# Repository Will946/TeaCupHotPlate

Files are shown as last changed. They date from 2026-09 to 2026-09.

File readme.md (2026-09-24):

**Tea Cozy Hotplate**
=====================================

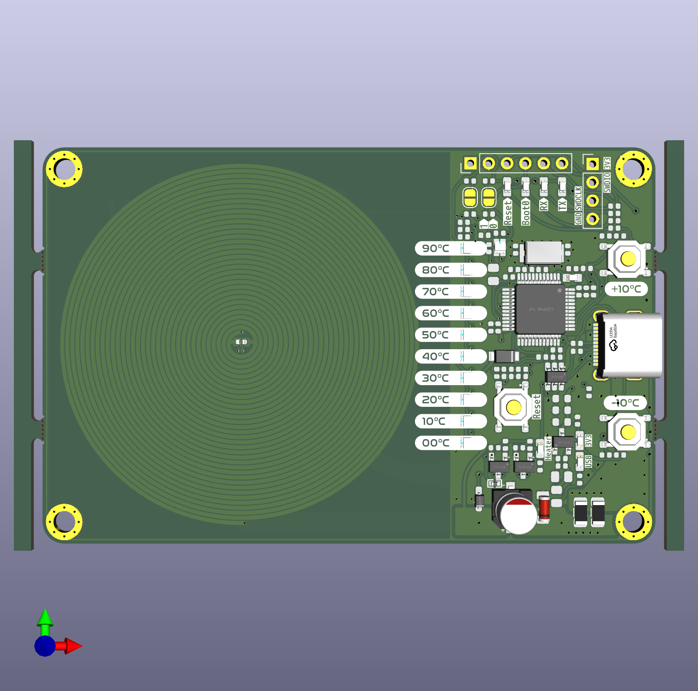
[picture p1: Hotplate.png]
PCB Render

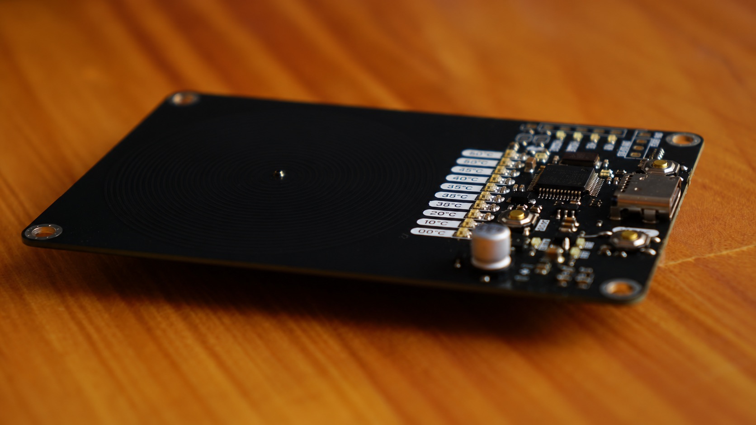
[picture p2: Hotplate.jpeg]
PCB Photo


### Overview

The Tea Cozy Hotplate is a USB-C powered, closed-loop temperature-controlled hotplate sized to sit under a single cup of tea. An STM32F103C8T6 ("Blue Pill" class MCU) reads a thermistor bonded to the underside of the heating coil, PWM drives two low-side NMOS switches to regulate power into a spiral PCB heater trace, and reports the current setpoint on a ten segment WS2812B ("Neopixel") LED bar that doubles as a 0 to 90 degrees C temperature dial. Two buttons let you nudge the setpoint up or down in 10 degree steps, and the whole board is bus powered off a single USB-C cable, with no separate power brick required.

### How It Works
**Power in.** 5V arrives on the USB-C receptacle (`J2`), passes through a pair of 1.5A resettable (PTC) fuses on VBUS, and is clamped by an `SRV05` ESD protection array on D+/D- and the CC lines. A single 2.2 ohm sense resistor pair plus 5.1kΩ pull downs on CC1/CC2 tell the upstream USB-C source the board is a fixed 5V/1.4A(ish) legacy sink. There is no PD negotiation chip, just resistor based CC termination, so any 5V USB-C source works. A `XC6206P332MR` LDO steps 5V down to a clean 3.3V rail for the MCU, LEDs, and sensors. A Zener (`D2`, ZMM5V6) sits across VBUS as extra transient protection.

**The heater.** The "hotplate" itself is not a separate component, it is a spiral trace etched directly into the PCB copper, measuring roughly 3.75 ohms in the assembled board, generated in KiCad with its built in Coil Generator tool (see the JLCPCB Heater Coil section below for the exact settings and trace math). Two `AO3400A` N-channel MOSFETs (`U3`/`U4`) sit low side between the coil and ground, each gated through a 4.7kΩ series resistor off the MCU's `Hotplate_EN` PWM line (rated for up to about 33kHz switching per the schematic notes). A flyback diode (`D1`, 1N5819WS Schottky) protects the switches from inductive kickback. The STM32 runs a PWM duty cycle proportional to the error between the setpoint and the measured coil temperature, essentially a bang bang or PID control loop over a resistive heater, similar to a soldering iron controller.

**Temperature sensing.** Two 47kΩ NTC thermistors are read as simple resistor divider ADC inputs. One (`Temp_Coil`) is thermally bonded near the heating coil to close the control loop, and a second (`Temp_Mosfet`) monitors the driver FETs so firmware can back off PWM if the switches themselves start overheating, giving thermal protection headroom beyond just controlling cup temperature.

**Display and setpoint.** Ten `WS2812B` addressable RGB LEDs, one per 10 degree step from 0 to 90 degrees C, are chained off a single data line (`Neopixel_Bus`) driven directly by an MCU GPIO, with no separate LED driver IC needed. Two tactile buttons (`SW2`/`SW3`, "Up"/"Down" in the schematic) step the setpoint in 10 degree increments, and the firmware lights LEDs up to the current setpoint.

**Programming and debug.** The board exposes both an SWD header (`SWDIO`/`SWDCLK`/GND/3V3) for use with an ST-Link V2, and a separate serial header (`MCU_TX`/`MCU_RX`/`Reset`/`BOOT0`) with its own status LEDs, so firmware can be flashed over SWD or bootloaded over UART without opening a case. Dedicated `Reset` and `BOOT0` push buttons plus solder jumpers (`JP1`/`JP2`) let you force the STM32 into its UART bootloader without needing to touch the board with tweezers.

### Features

* Closed-loop temperature control, plus or minus 2 degrees C accuracy
* Compact design fits most tea cups
* 10 segment addressable LED bargraph for setpoint/temperature display (0 to 90 degrees C in 10 degree steps)
* Up/down buttons for setpoint adjustment
* Powered entirely via USB-C (5V, about 1.4A budget, PTC fused)
* Dual NTC thermistors, one for coil temp (control loop), one for driver FET temp (protection)
* STM32F103C8T6 microcontroller, 72MHz Arm Cortex-M3
* Dedicated SWD and UART programming headers with BOOT0/Reset buttons for field reflashing

### Specifications

#### STM32 Specifications

* **CPU**: Arm Cortex-M3 @ 72MHz
* **Flash**: 64KB
* **RAM**: 20KB
* **Package**: LQFP-48

#### Components

* **Microcontroller**: STM32F103C8T6
* **LDO Regulator**: XC6206P332MR (5V to 3.3V)
* **ESD Protection**: SRV05 (USB D+/D-, CC1/CC2)
* **Fuse**: 2 x 1.5A Resettable Fuses (VBUS)
* **USB Connector**: USB-C Receptacle
* **Heater Driver**: 2 x AO3400A NMOS (low-side switching), 4.7kΩ gate resistors, 1N5819WS flyback diode
* **Heating Element**: ~3.75Ω Spiral PCB Coil (34 turns, 1 layer, 50mm outer diameter, 0.55mm trace width, 0.15mm spacing)
* **Temperature Sensors**: 2 x 47kΩ NTC Thermistor (coil + driver FET)
* **Display**: 10 x WS2812B addressable RGB LEDs (0-90°C bargraph)
* **User Input**: Up/Down setpoint buttons, Reset button, BOOT0 button

### Assembly and Programming

* Program the STM32 microcontroller using an ST-Link V2 via the SWDIO header, or bootload over the UART header (`MCU_TX`/`MCU_RX`) using the `BOOT0`/`Reset` buttons or `JP1`/`JP2` jumpers to force bootloader mode.

## JLCPCB Heater Coil (1mm PCB with 1oz/ft^2)

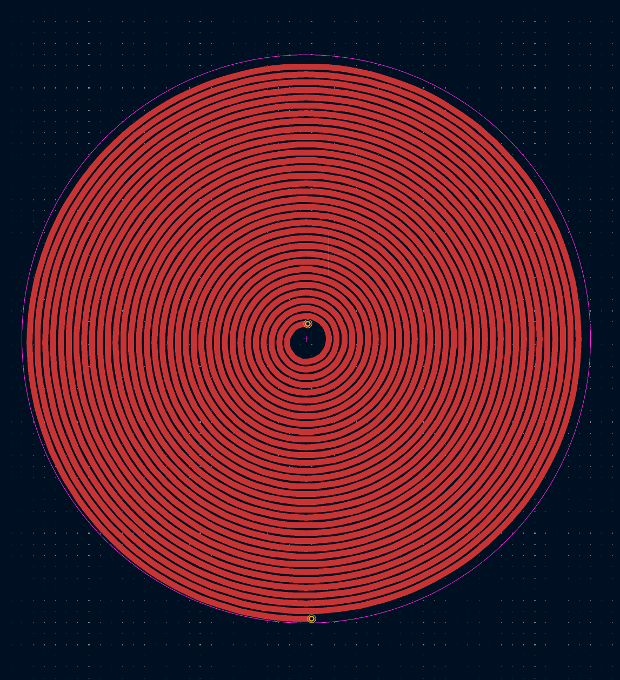
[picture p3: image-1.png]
Heater Coil PCB Trace

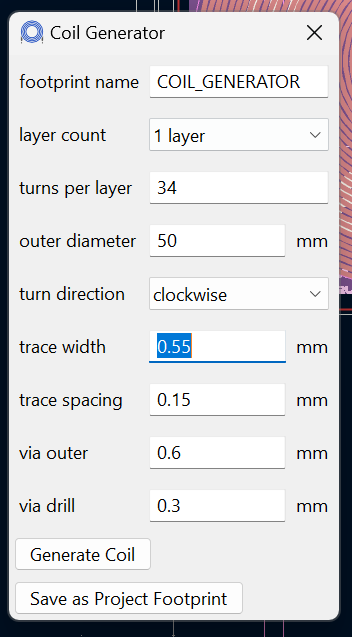
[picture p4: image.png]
KiCad Coil Generator Settings


* **Trace**: 2.8m length, 0.55mm width, 1oz/ft^2
* **Calculated Resistance**: 2.47Ω (assuming 0.000017Ω.mm)
* **Real-World Resistance**: 3.75Ω (calculated to be 0.0000258Ω.mm)

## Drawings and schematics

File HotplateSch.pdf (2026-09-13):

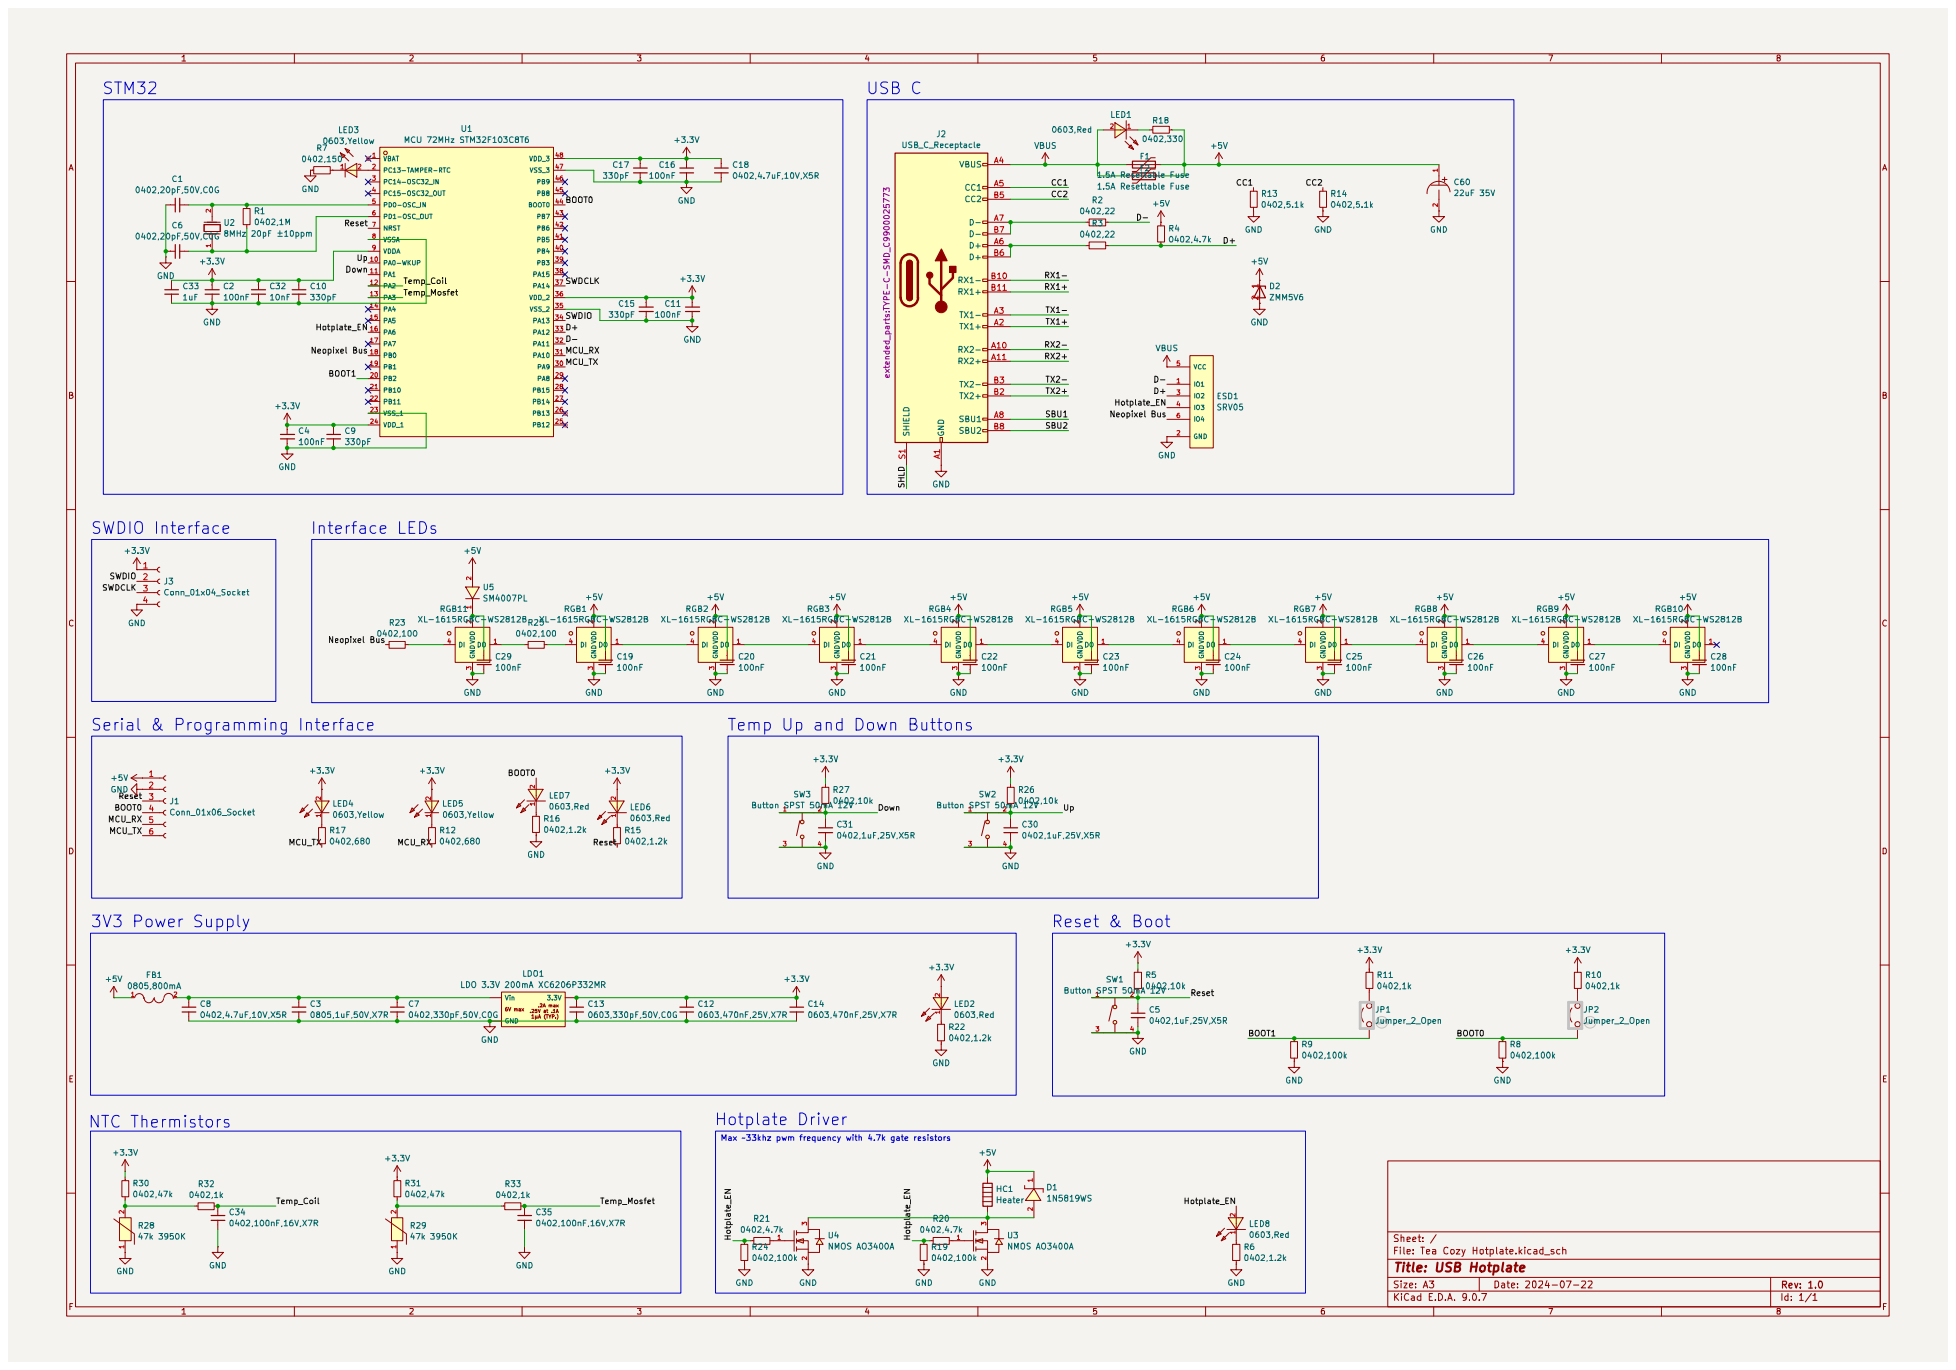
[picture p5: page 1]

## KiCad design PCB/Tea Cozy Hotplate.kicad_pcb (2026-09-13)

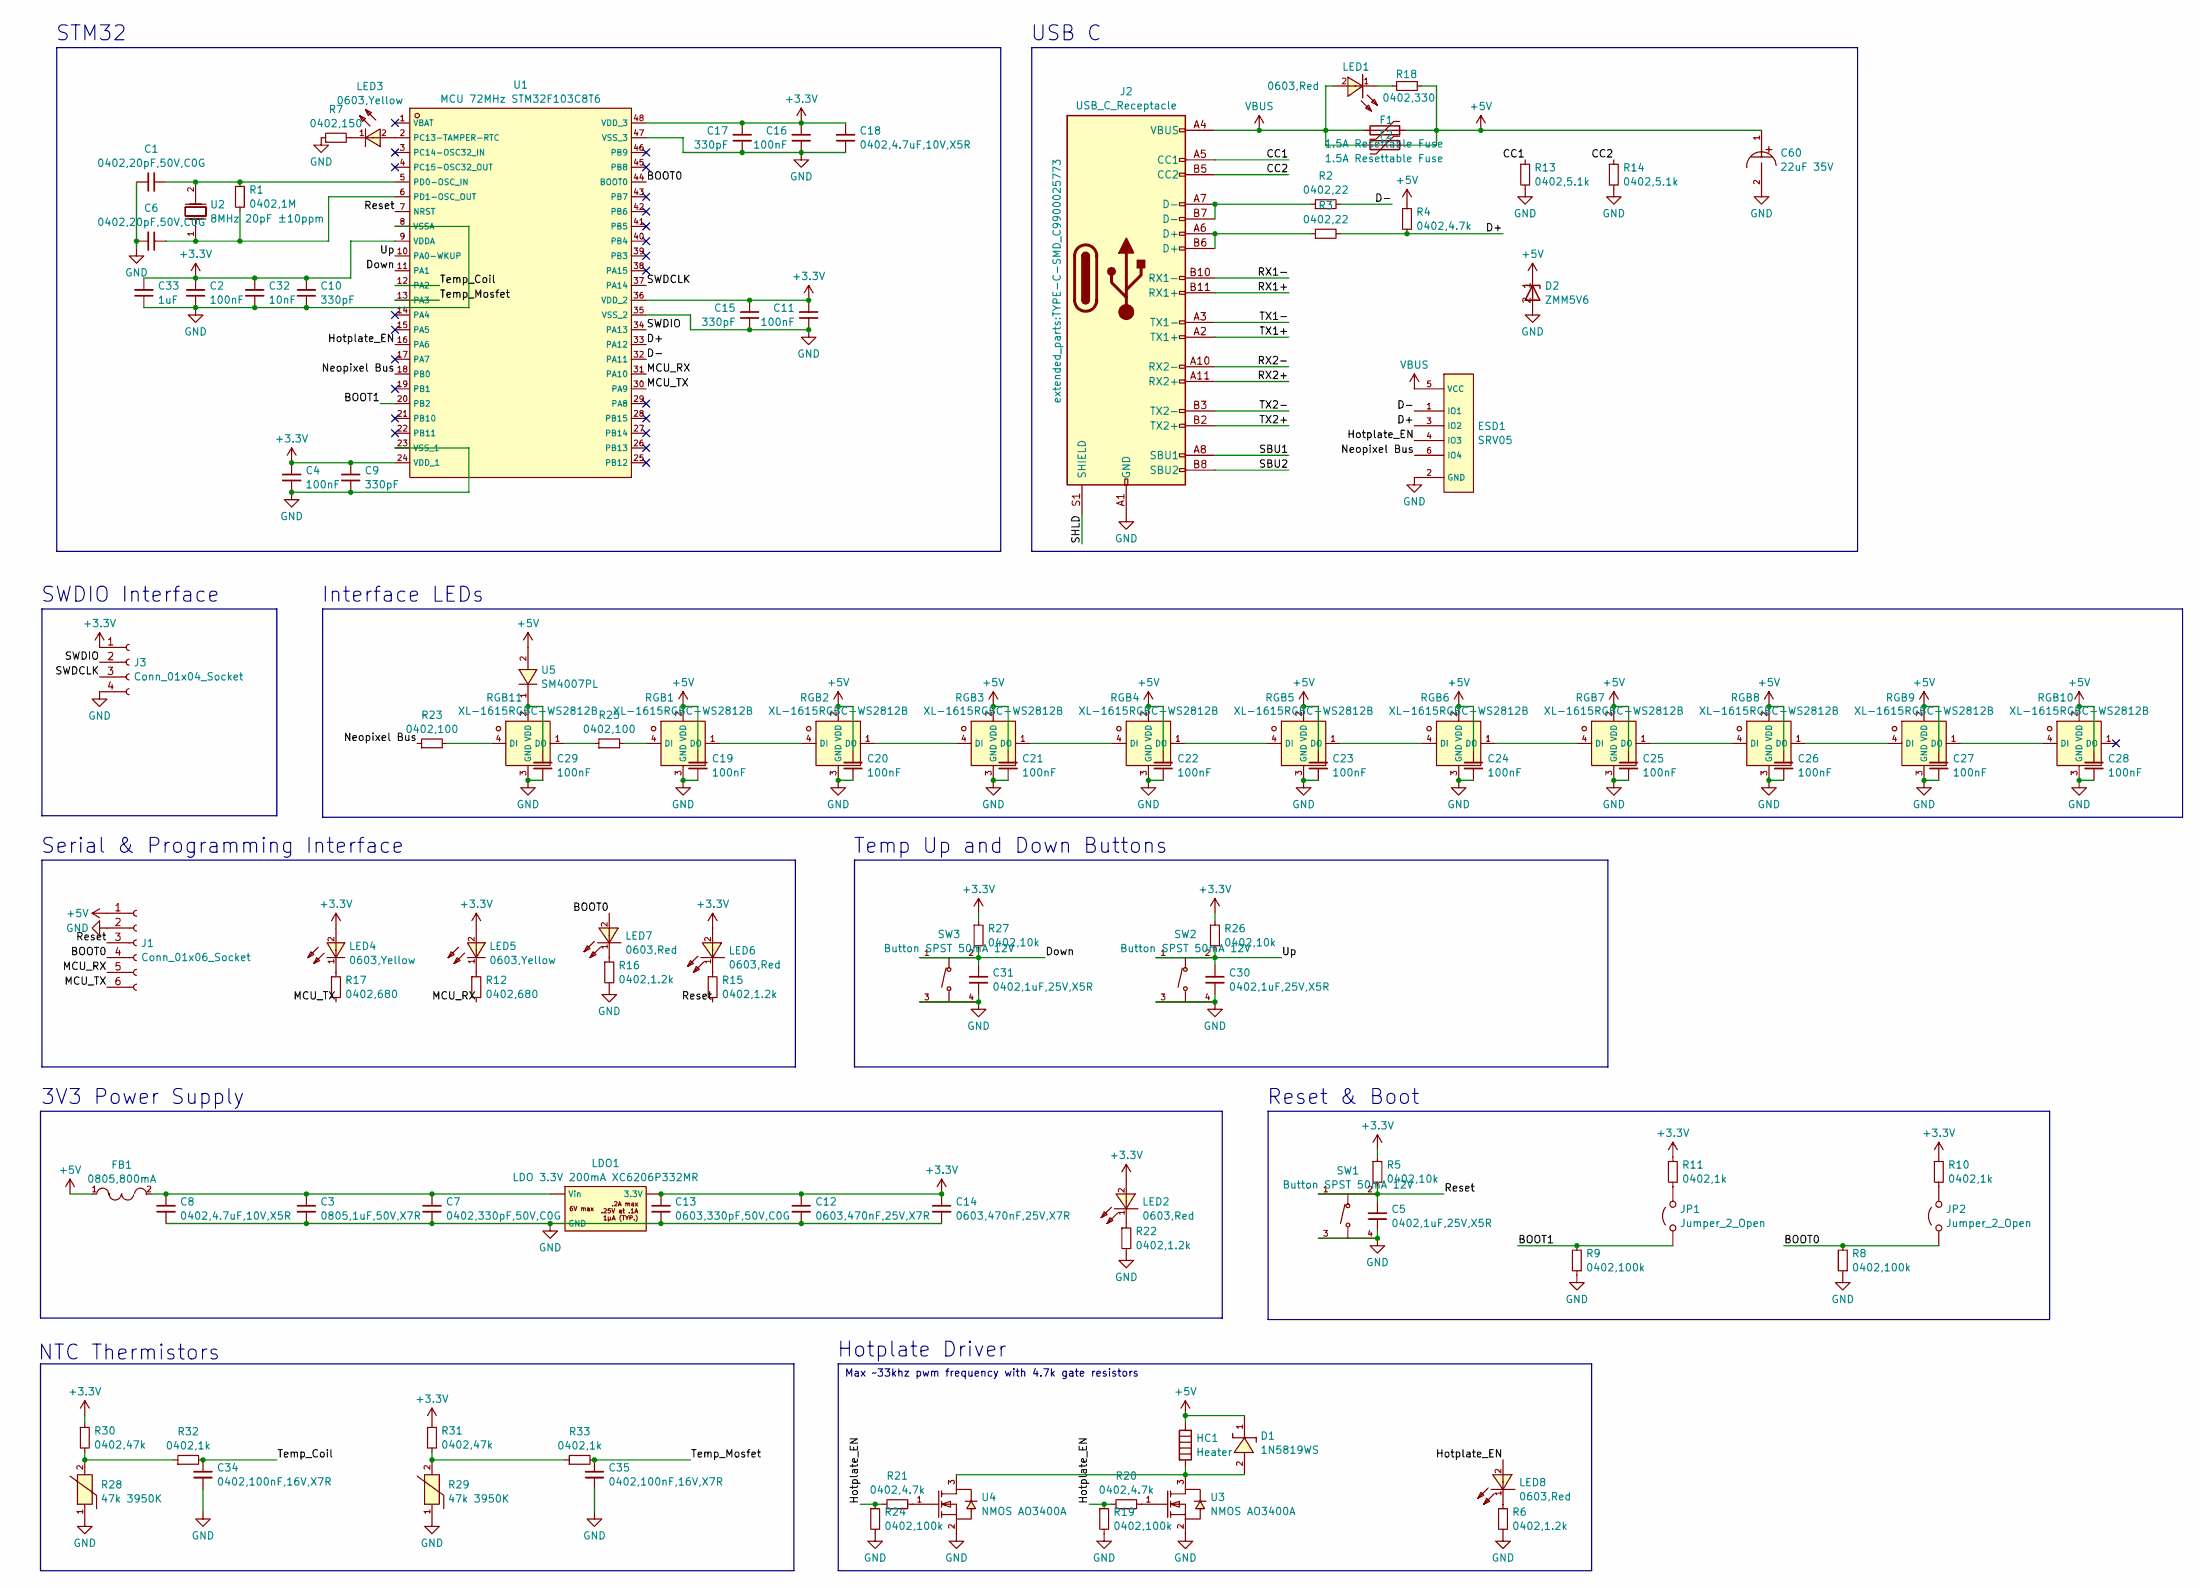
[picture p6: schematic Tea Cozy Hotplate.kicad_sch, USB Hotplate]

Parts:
C1, C6: 0402,20pF,50V,C0G; 0402_1005Metric; MFGPN 0402CG200J500NT; LCSC C1554
C2, C4, C11, C16, C19, C20, C21, C22, C23, C24, C25, C26, C27, C28, C29: 100nF; 0402_1005Metric; MFGPN CL05B104KO5NNNC; LCSC C1525
C3: 0805,1uF,50V,X7R; 0805_2012Metric; MFGPN CL21B105KBFNNNE; LCSC C28323
C5, C30, C31: 0402,1uF,25V,X5R; 0402_1005Metric; MFGPN CL05A105KA5NQNC; LCSC C52923
C7: 0402,330pF,50V,C0G; 0402_1005Metric; MFGPN CL05C331JB5NNNC; LCSC C13533
C8, C18: 0402,4.7uF,10V,X5R; 0402_1005Metric; MFGPN CL05A475MP5NRNC; LCSC C23733
C9, C10, C15, C17: 330pF; 0402_1005Metric; MFGPN CL05C331JB5NNNC; LCSC C13533
C12, C14: 0603,470nF,25V,X7R; 0603_1608Metric; MFGPN CL10B474KA8NNNC; LCSC C1623
C13: 0603,330pF,50V,C0G; 0603_1608Metric; MFGPN CL10C331JB8NNNC; LCSC C1664
C32: 10nF; 0402_1005Metric; MFGPN CL05B103KB5NNNC; LCSC C15195
C33: 1uF; 0805_2012Metric; MFGPN CL21B105KBFNNNE; LCSC C28323
C34, C35: 0402,100nF,16V,X7R; 0402_1005Metric; MFGPN CL05B104KO5NNNC; LCSC C1525
C60: 22uF 35V; CAP-SMD_BD5.0-L5.3-W5.3-LS6.0-FD; LCSC C2887274
D1: 1N5819WS; SOD-323_L1.8-W1.3-LS2.5-RD; LCSC C191023
D2: ZMM5V6; LL-34_L3.5-W1.5-RD; LCSC C8062
ESD1: SRV05; SOT-23-6_L2.9-W1.6-P0.95-LS2.8-BR; LCSC C85364
F1, F2: 1.5A Resettable Fuse; Fuse_1206_3216Metric; LCSC C2838983
FB1: 0805,800mA; 0805_2012Metric; LCSC C1015
HC1: Heater; heater_coil
J1: Conn_01x06_Socket; PinHeader_1x06_P2.54mm_Vertical
J2: USB_C_Receptacle; TYPE-C-SMD_C9900025773; LCSC C5156605
J3: Conn_01x04_Socket; PinHeader_1x04_P2.54mm_Vertical
JP1, JP2: Jumper_2_Open; SolderJumper-2_P1.3mm_Open_RoundedPad1.0x1.5mm
LDO1: LDO 3.3V 200mA XC6206P332MR; SOT-23-3_L2.9-W1.6-P1.90-LS2.8-BR; LCSC C5446
LED1, LED2, LED6, LED7, LED8: 0603,Red; LED0603; LCSC C2286
LED3, LED4, LED5: 0603,Yellow; LED0603; LCSC C72038
R1: 0402,1M; 0402_1005Metric; MFGPN 0402WGF1004TCE; LCSC C26083
R2, R3: 0402,22; 0402_1005Metric; MFGPN 0402WGF220JTCE; LCSC C25092
R4, R20, R21: 0402,4.7k; 0402_1005Metric; MFGPN 0402WGF4701TCE; LCSC C25900
R5, R26, R27: 0402,10k; 0402_1005Metric; MFGPN 0402WGF1002TCE; LCSC C25744
R6, R15, R16, R22: 0402,1.2k; 0402_1005Metric; MFGPN 0402WGF1201TCE; LCSC C25862
R7: 0402,150; 0402_1005Metric; MFGPN 0402WGF1500TCE; LCSC C25082
R8, R9, R19, R24: 0402,100k; 0402_1005Metric; MFGPN 0402WGF1003TCE; LCSC C25741
R10, R11, R32, R33: 0402,1k; 0402_1005Metric; MFGPN 0402WGF1001TCE; LCSC C11702
R12, R17: 0402,680; 0402_1005Metric; MFGPN 0402WGF6800TCE; LCSC C25130
R13, R14: 0402,5.1k; 0402_1005Metric; MFGPN 0402WGF5101TCE; LCSC C25905
R18: 0402,330; 0402_1005Metric; MFGPN 0402WGF3300TCE; LCSC C25104
R23, R25: 0402,100; 0402_1005Metric; MFGPN 0402WGF1000TCE; LCSC C25076
R28, R29: 47k 3950K; R0402; LCSC C2991699
R30, R31: 0402,47k; 0402_1005Metric; MFGPN 0402WGF4702TCE; LCSC C25792
RGB1, RGB2, RGB3, RGB4, RGB5, RGB6, RGB7, RGB8, RGB9, RGB10, RGB11: XL-1615RGBC-WS2812B; LED-SMD_4P-L1.6-W1.5_XL-1615RGBC-WS2812B; LCSC C5349954
SW1, SW2, SW3: Button SPST 50mA 12V; SW-SMD_4P-L5.1-W5.1-P3.70-LS6.5-TL-2; LCSC C318884
U1: MCU 72MHz STM32F103C8T6; LQFP-48_L7.0-W7.0-P0.50-LS9.0-BL; LCSC C8734
U2: 8MHz 20pF ±10ppm; CRYSTAL-SMD_L5.0-W3.2; LCSC C115962
U3, U4: NMOS AO3400A; SOT-23-3_L2.9-W1.6-P1.90-LS2.8-BR; LCSC C20917
U5: SM4007PL; SOD-123F_L2.8-W1.8-LS3.7-RD; LCSC C64898

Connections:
+3.3V: C2.1, C4.1, C9.1, C10.1, C11.1, C12.1, C13.1, C14.1, C15.1, C16.1, C17.1, C18.1, C32.1, C33.1, J3.1, LDO1.3 (3.3V), LED2.2 (A), LED4.2 (A), LED5.2 (A), LED6.2 (A), R5.1, R10.1, R11.1, R26.1, R27.1, R30.1, R31.1, U1.9 (VDDA), U1.24 (VDD_1), U1.36 (VDD_2), U1.48 (VDD_3)
+5V: C19.1, C20.1, C21.1, C22.1, C23.1, C24.1, C25.1, C26.1, C27.1, C28.1, C60.1, D1.1 (C), D2.1 (K), F1.1, F2.1, FB1.1, HC1.1, J1.1, R4.1, R18.1, RGB1.2 (VDD), RGB2.2 (VDD), RGB3.2 (VDD), RGB4.2 (VDD), RGB5.2 (VDD), RGB6.2 (VDD), RGB7.2 (VDD), RGB8.2 (VDD), RGB9.2 (VDD), RGB10.2 (VDD), U5.2 (A)
/BOOT0: J1.4, JP2.1 (A), LED7.2 (A), R8.2, U1.44 (BOOT0)
/BOOT1: JP1.1 (A), R9.2, U1.20 (PB2)
/CC1: J2.A5 (CC1), R13.1
/CC2: J2.B5 (CC2), R14.1
/D+: ESD1.3 (IO2), R3.2, R4.2, U1.33 (PA12)
/D-: ESD1.1 (IO1), R2.2, U1.32 (PA11)
/Down: C31.1, R27.2, SW3.1 (A), SW3.2 (B), U1.11 (PA1)
/Hotplate_EN: ESD1.4 (IO3), LED8.2 (A), R19.1, R20.1, R21.1, R24.1, U1.16 (PA6)
/MCU_RX: J1.5, R12.2, U1.31 (PA10)
/MCU_TX: J1.6, R17.2, U1.30 (PA9)
/Neopixel Bus: ESD1.6 (IO4), R23.1, U1.18 (PB0)
/RX1+: J2.B11 (RX1+)
/RX1-: J2.B10 (RX1-)
/RX2+: J2.A11 (RX2+)
/RX2-: J2.A10 (RX2-)
/Reset: C5.1, J1.3, R5.2, R15.2, SW1.1 (A), SW1.2 (B), U1.7 (NRST)
/SBU1: J2.A8 (SBU1)
/SBU2: J2.B8 (SBU2)
/SHLD: J2.S1 (SHIELD)
/SWDCLK: J3.3, U1.37 (PA14)
/SWDIO: J3.2, U1.34 (PA13)
/TX1+: J2.A2 (TX1+)
/TX1-: J2.A3 (TX1-)
/TX2+: J2.B2 (TX2+)
/TX2-: J2.B3 (TX2-)
/Temp_Coil: C34.1, R32.2, U1.12 (PA2)
/Temp_Mosfet: C35.1, R33.2, U1.13 (PA3)
/Up: C30.1, R26.2, SW2.1 (A), SW2.2 (B), U1.10 (PA0-WKUP)
GND: C1.1, C2.2, C3.2, C4.2, C5.2, C6.1, C7.2, C8.2, C9.2, C10.2, C11.2, C12.2, C13.2, C14.2, C15.2, C16.2, C17.2, C18.2, C19.2, C20.2, C21.2, C22.2, C23.2, C24.2, C25.2, C26.2, C27.2, C28.2, C29.2, C30.2, C31.2, C32.2, C33.2, C34.2, C35.2, C60.2, D2.2 (A), ESD1.2 (GND), J1.2, J2.A1 (GND), J2.A12 (GND), J2.B1 (GND), J2.B12 (GND), J3.4, LDO1.1 (GND), R6.2, R7.1, R8.1, R9.1, R13.2, R14.2, R16.2, R19.2, R22.2, R24.2, R28.1, R29.1, RGB1.3 (GND), RGB2.3 (GND), RGB3.3 (GND), RGB4.3 (GND), RGB5.3 (GND), RGB6.3 (GND), RGB7.3 (GND), RGB8.3 (GND), RGB9.3 (GND), RGB10.3 (GND), RGB11.3 (GND), SW1.3 (C), SW1.4 (D), SW2.3 (C), SW2.4 (D), SW3.3 (C), SW3.4 (D), U1.8 (VSSA), U1.23 (VSS_1), U1.35 (VSS_2), U1.47 (VSS_3), U3.2 (S), U4.2 (S)
unnamed: D1.2 (A), HC1.2, U3.3 (D), U4.3 (D)
unnamed: J2.A6 (D+), J2.B6 (D+), R3.1
unnamed: J2.A7 (D-), J2.B7 (D-), R2.1
unnamed: JP1.2 (B), R11.2
unnamed: JP2.2 (B), R10.2
unnamed: C3.1, C7.1, C8.1, FB1.2, LDO1.2 (Vin)
unnamed: LED1.1 (K), R18.2
unnamed: LED2.1 (K), R22.1
unnamed: LED3.2 (A), U1.2 (PC13-TAMPER-RTC)
unnamed: LED3.1 (C), R7.2
unnamed: LED4.1 (C), R17.1
unnamed: LED5.1 (C), R12.1
unnamed: LED6.1 (K), R15.1
unnamed: LED7.1 (K), R16.1
unnamed: LED8.1 (K), R6.1
unnamed: R28.2, R30.2, R32.1
unnamed: R29.2, R31.2, R33.1
unnamed: R25.2, RGB1.4 (DI)
unnamed: RGB1.1 (DO), RGB2.4 (DI)
unnamed: RGB2.1 (DO), RGB3.4 (DI)
unnamed: RGB3.1 (DO), RGB4.4 (DI)
unnamed: RGB4.1 (DO), RGB5.4 (DI)
unnamed: RGB5.1 (DO), RGB6.4 (DI)
unnamed: RGB6.1 (DO), RGB7.4 (DI)
unnamed: RGB7.1 (DO), RGB8.4 (DI)
unnamed: RGB8.1 (DO), RGB9.4 (DI)
unnamed: RGB9.1 (DO), RGB10.4 (DI)
unnamed: R23.2, RGB11.4 (DI)
unnamed: R25.1, RGB11.1 (DO)
unnamed: C29.1, RGB11.2 (VDD), U5.1 (C)
unnamed: C1.2, R1.1, U1.5 (PD0-OSC_IN), U2.2 (OSC2)
unnamed: C6.2, R1.2, U1.6 (PD1-OSC_OUT), U2.1 (OSC1)
unnamed: R20.2, U3.1 (G)
unnamed: R21.2, U4.1 (G)
VBUS: ESD1.5 (VCC), F1.2, F2.2, J2.A4 (VBUS), J2.A9 (VBUS), J2.B4 (VBUS), J2.B9 (VBUS), LED1.2 (A)

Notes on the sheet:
3V3 Power Supply
USB C
NTC Thermistors
Serial & Programming Interface
SWDIO Interface
Hotplate Driver
Interface LEDs
Max ~33khz pwm frequency with 4.7k gate resistors
STM32
Reset & Boot
Temp Up and Down Buttons

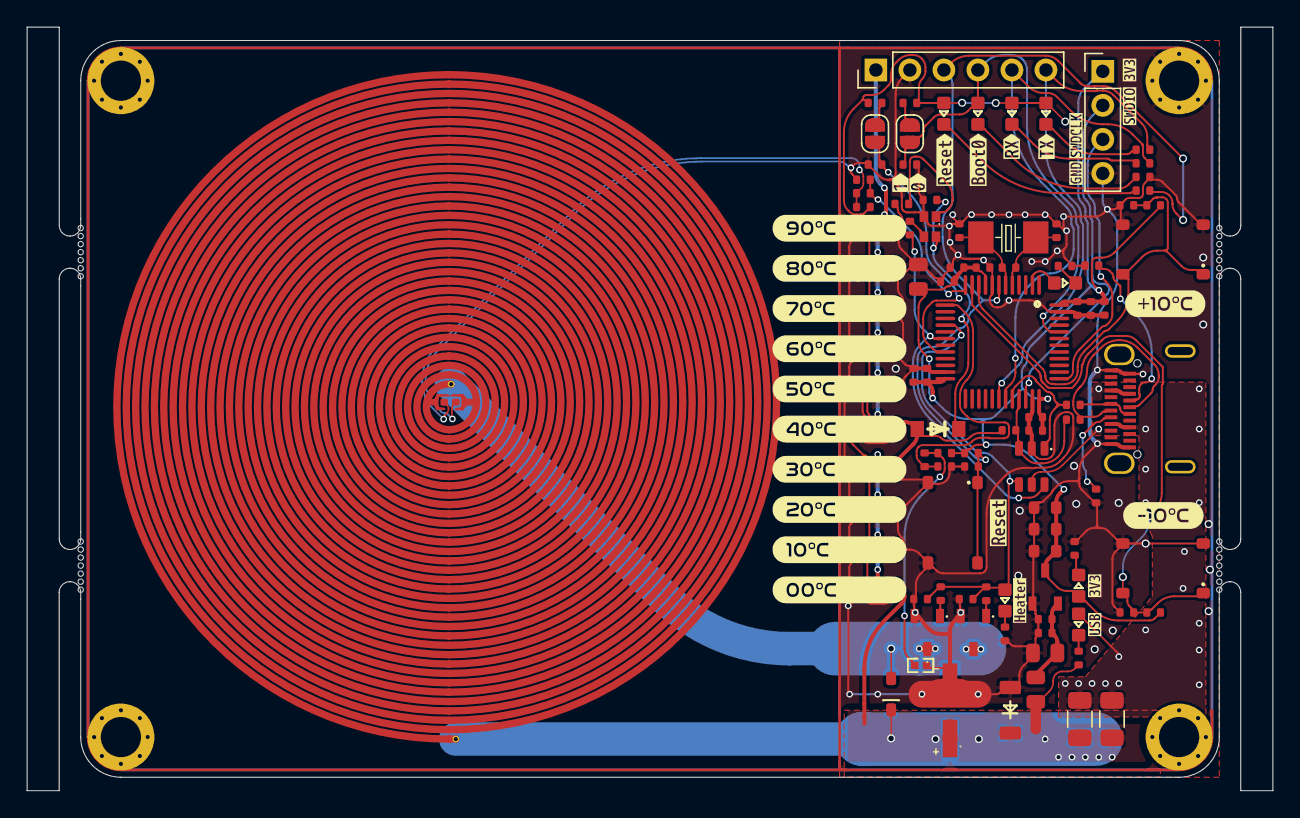
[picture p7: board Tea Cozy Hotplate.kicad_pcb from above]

Board: 2 copper layers, 93.0 x 57.0 mm, 127 parts (0 on the bottom side), 55 nets.

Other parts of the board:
M1, M2, M3, M4: MountingHole_3.2mm_M3
kibuzzard-669770AA: G***; kibuzzard-669770AA
kibuzzard-669770B6: G***; kibuzzard-669770B6
kibuzzard-669770CC: G***; kibuzzard-669770CC
kibuzzard-669770DC: G***; kibuzzard-669770DC
kibuzzard-669771D1: G***; kibuzzard-669771D1
kibuzzard-669771DB: G***; kibuzzard-669771DB
kibuzzard-6697705A: G***; kibuzzard-6697705A
kibuzzard-6697709F: G***; kibuzzard-6697709F
kibuzzard-6697716D: G***; kibuzzard-6697716D
kibuzzard-6697719B: G***; kibuzzard-6697719B
kibuzzard-66977083: G***; kibuzzard-66977083
kibuzzard-66977187: G***; kibuzzard-66977187
kibuzzard-66977193: G***; kibuzzard-66977193
kibuzzard-66977218: G***; kibuzzard-66977218
